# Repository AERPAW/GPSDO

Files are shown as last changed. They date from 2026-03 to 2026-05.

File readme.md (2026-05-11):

# AERPAW GPSDO

This repository contains the firmware, host utilities and design files for the AERPAW GPSDO.

The firmware is available in `firmware/` and the status utility in `gpsdo_status/`. See the readme in each for more information.

Install `gpsdo_cli` on Linux:

```sh
curl -fsSL https://raw.githubusercontent.com/AERPAW/GPSDO/main/gpsdo_cli/gpsdo_cli.py | sudo install -m 0755 /dev/stdin /usr/local/bin/gpsdo_cli
```

If `gpsdo_cli` cannot access `/dev/ttyACM*`, add your user to the serial device group and log out/in:

```sh
sudo usermod -aG dialout "$USER"
```

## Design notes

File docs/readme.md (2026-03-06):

# GPSDO Rev. 4.0 Documentation

## Overview

This document describes the 4th revision of the AERPAW GPSDO as well as the associated firmware and software. First, the hardware is described and all its function blocks are explained in detail. Then, the process of assembling and testing the GPSDO is explained. The firmware and host software, as well as the way to compile them is then finally explained.

TODO: Picture

## Hardware

This section describes the GPSDO hardware, a picture of which is shown below. A full schematic of the board can be found in the KiCad files.

TODO: Picture

- **10MHz Connector:** The 10MHz connector provides a 10MHz refernce signal for use by a USRP or other SDR.
- **1PPS Connector:** The 1-Pulse-Per-Second (1PPS) connector provides a pulse every second. This signal is 3.3V CMOS.
- **OCXO Data LED:** The OCXO Data LED blinks when data is exchanged between the OCXO module and host PC.
- **GNSS Data LED:** The GNSS Data LED blinks when data is exchanged between the GNSS module and host PC.
- **1PPS LED:** The 1PPS LED blinks once per second in phase with the 1PPS output.
- **OCXO Lock LED:** The OCXO Lock LED lights up when the OCXO has been able to lock onto the 1PPS signal from the GNSS module.
- **Power LED:** The power LED lights up any time the board receives power from either USB or the power connector.
- **USB Connector:** The USB connector allows a host computer to communicate with the on-board GNSS and OCXO modules.
- **Power Connector:** The power connector is used to provide 5 to 15V to the GPSDO.

### Theory of Operation

This section describes the inner workings of the GPSDO hardware, a block diagram of which is shown below. First, the power section and various safety features are described. Then, the GNSS and OCXO modules are described and the choice to use an external GNSS module is explained. Finally, the microcontroller section and its components is described.

TODO: Block diagram

#### Power Section

The power section takes 5 to 15V, either from the dedicated power connector or USB, filters it to attenuated noise from the incoming supply and regulates it down to 3.3V. The filter is implemented as simple common-mode choke. The power section also includes a series of protection features to ensure reliability and resiliance to mishandling. The incoming power is directed through a Schottky diode, a polyfuse and then is clamped by a 15V TVS diode. In the event that the board is powered in the wrong polarity, the board will simply not power on and no damage will be made. In the event that the 15V voltage limit is exceeded, the the TVS diode clamps it and the high resulting high current trips the polyfuse. Since polyfuses self reset when power is removed for a certain amount of time, no lasting damage is done. The schematic of the power section is as shown below.

TODO: Schematic.

#### GNSS Module

The GNSS module is an off-the-shelf SparkFun ZED-F9T breakout board. It's job is to receive GPS signals from the antenna connected to its input and generate a 1-Pulse-Per-Second (1PPS) signal that the OCXO module discussed further down can lock onto to generate a stable 10MHz. The module communicates with the microcontroller over a UART connection operating at 38400baud 8n1 (8bits, no parity, 1 stop bit).

#### OCXO Module

The OCXO module is actually originally an entire GPSDO in itself. Unfortunately, the GNSS portion of it was not satisfactory, so the external GNSS module is used to provide it with a 1PPS signal that it can lock onto. The module then generates a 10MHz signal from which it generates its own 1PPS signal. By comparing the phase of its 1PPS signal to the one from the GNSS module, it is able to steer the frequency of its oscillator slowly until the 1PPS signals are phase locked together. When this occurs, the Lock LED on the board lights up and the GPSDO is ready for operation. The OCXO module communicates with the microcontroller over a UART connections operating at 115200baud 8n1.

#### Microcontroller

The microcontroller is a Raspberry Pi RP2040. Its job is to relay the communication from the GNSS and OCXO modules to the host computer through a USB interface. It loads its firmware from the on-board flash memory and gets its clock from a separate 12MHz oscillator.

### Assembly

This section describes the process of assembling the GPSDO hardware from blank PCBs and components. This process can be summarized as follows: First, solder paste is applied to the PCB with the help of a stencil. Next, the intergrated circuits are placed, followed by small passives, then larger passives and finally the SMA connectors. The board can then be reflowed, after which the through-hole components can be soldered in manually. At this stage, the 3.3V voltage rail is checked and, if within the allowable range, the GNSS and OCXO modules are installed.

In general, it is recommended to have a computer on hand with the KiCad files open to be able to quickly find the location and orientation of all components. It is also helpful to figure out which traces carry which signals if debugging is necessary.

#### Solder Paste Application

The solder paste is applied using a solder paste stencil. This is simply a thin piece of stainless steel with precisely cut holes which are designed to let a specific quantity of solder paste in specific areas. To use the stencil, it is recommended to build a holding jig with other PCBs to hold the blank GPSDO PCB in place while the stencil is lowered onto it and solder paste is applied as shown in the picture below.

TODO: Picture

The paste can then be applied by first laying down a beed of solder paste onto one side of the stencil and dragging it across using a Squeegee as sown in the picture below.

TODO: Picture

The stencil can then be lifted revealing the paste applied to the pads on the PCB.

#### Placing the Integrated Circuits

Once the solder paste has been applied, the first components to be placed are the integrated circuits. This is done because they have a very small pin pitch and thus require a decent amount of precision to place. Having other components already on the board could make this more difficult. The board was designed such that all ICs are in the exact same orientation, with pin 1 oriented towards the top-left corner of the board, aka. the corner with the large power connector. The integrated circuits to place are as shown in the picture below.

TODO: Picture

#### Placing the Small Passives

After the integrated circuits are placed, all the 0805-sized passives can be placed. This includes all decoupling capacitors around the MCU, all resistors, a few small diodes and the polyfuse. The small passives are shown in the picture below.

TODO: Picture

#### Placing the Large Passives

The next components to be placed are the larger passives. This includes the inductors, the large TVS diode and the large decoupling capacitors for the switching voltage regulator. These large passives are as shown in the picture below.

TODO: Picture

#### Placing the SMA Connectors

Once all other SMD components have been places, the SMA connectors can be placed. To do this, simply slide the connectors over the edge of the PCB and make sure they are aligned properly with the pads as shown in the picture below.

TODO: Picture

#### Reflowing

With all SMD components now placed, the board can be reflowed. This involves heating up the board to melt the solder paste. To do this, places the PCBs in the reflow oven with dummy PCBs serving as spacers to make sure the PCBs do not touch the botton of the reflow oven as shown in the picture below. Then, close the oven tray and start the reflow process.

TODO: Picture

Once the oven indicates that the reflow process is over, open the tray and wait a few minutes for the board to cool down further.

#### Checking for Solder Bridges

Manual solder paste application and component placement is not perfect. After reflow soldering, it is likely that solder bridges will be left, most often on the pins of the integrated circuits. If any bridges are found, DO NOT proceed further until they are remedied as described below.

#### Soldering the Through-Hole Components

Now that all SMD components have been soldered using reflow soldering, the through-hole components can be soldered manually. The throughole components are as shown in the picture below.

TODO: Picture

> [!CAUTION]
> DO NOT install the GNSS and OCXO modules at this stage. The voltage regulator could be defective and cause a high voltage to appear on the 3.3V rail. This could easily destroy the expensive GNSS and OCXO modules.

#### Verifying the 3.3V Rail

With all components solder, the board can now be powered from the power connector. A multimeter is then used to measure the 3.3V rail at the point shown in the picture below. The measured voltage must be in the range of 3.2 to 3.4V for the board to be considered working at this stage.

TODO: Picture

#### Ultrasonic Cleaning

Once the power section has been confirmed to be working, the board can be cleaned using the ultrasonic cleaner to remove all flux residue.

#### Installing the GNSS and OCXO modules

The last step in the assembly process is simply installing the GNSS and OCXO modules. While the GNSS module is straight foward to install, caution must be used when installing the OCXO module due to its thin pins that easily bend and break.

### Bring-Up

With the GPSDO fully assembled, power is applied through the power connector and the USB port is connected to a computer. The GPSDO should appear as a USB flash drive.

#### Flashing the firmware

To flash the firmware, simply drag and drop the .UF2 firmware file to the virtual USB flash drive. The board should then reboot, after which you should see two virtual serial ports.

#### Configuring the OCXO Module

Out of the box, the OCXO modules are not configured to lock from an external 1PPS. To configure this, open the serial port corresponding to the OCXO module in a virtual terminal and run the following commands:

```
SYNC?
SYNC:SOUR:MODE EXT
SYNC?
```

This configuration is stored in non-volatile memory on the module and thus only has to be done once. After this, the OCXO module should now attempt to lock onto the 1PPS signal from the GNSS module.

#### Troubleshooting

TODO

### Testing

TODO

## Firmware

This section describes the firmware of the GPSDO, that is the code that runs on the embedded microcontroller.

### Theory of Operation

### Compilation

## Software

### Theory of Operation

### Compilation

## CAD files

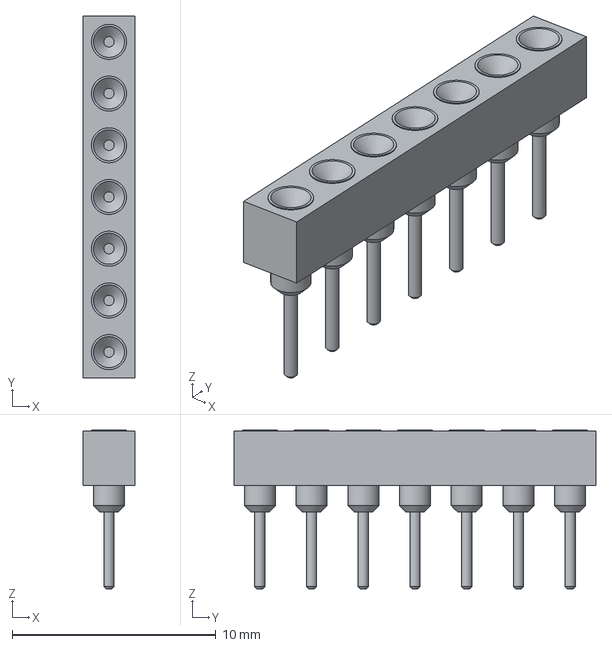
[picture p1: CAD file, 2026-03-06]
pcb/3d/sip7.step
2.54 x 17.8 x 7.79 mm

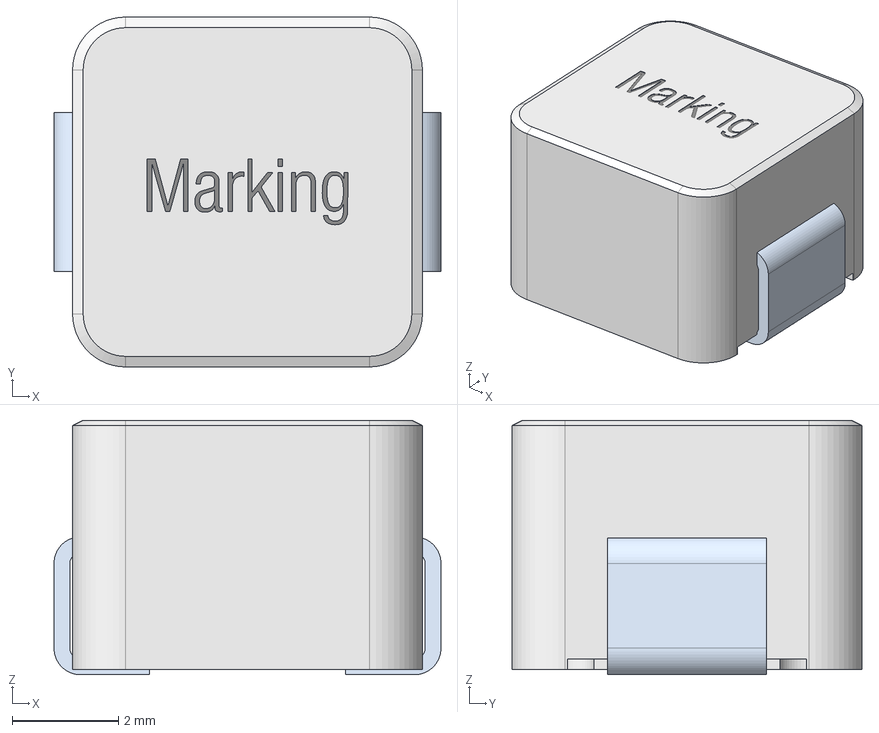
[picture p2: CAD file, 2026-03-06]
pcb/3d/WE-LHMI_7050LHMI (rev1).stp
7.30 x 6.60 x 4.80 mm

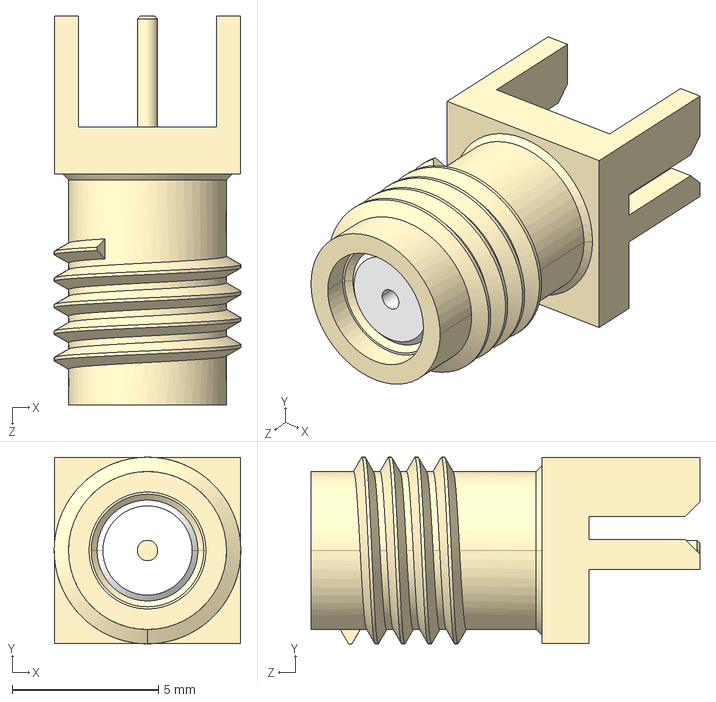
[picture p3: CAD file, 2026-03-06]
pcb/3d/EMPCB.SMAFSTJ.B.HT.STEP
6.38 x 6.38 x 13.3 mm

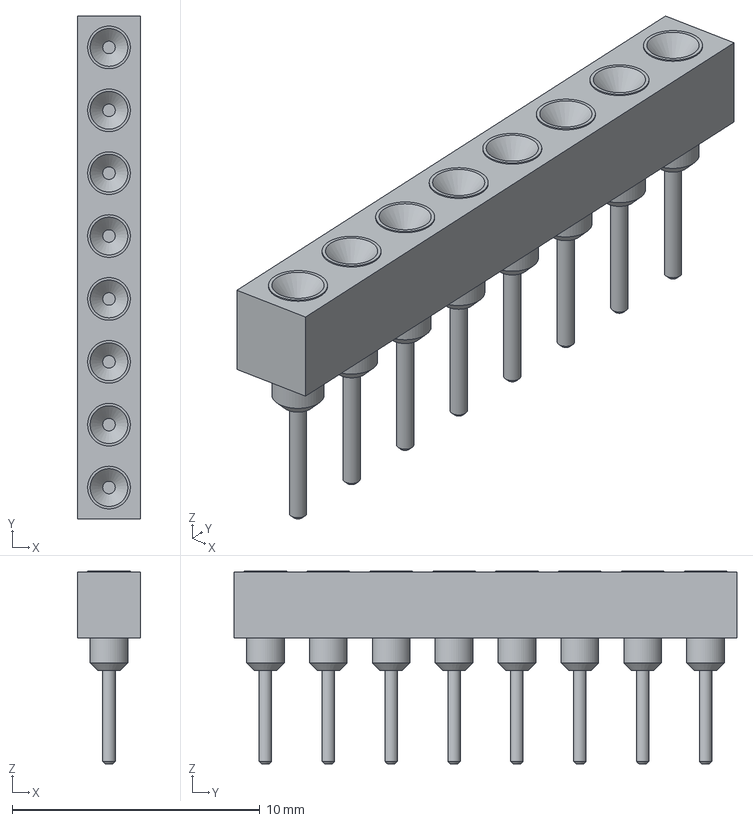
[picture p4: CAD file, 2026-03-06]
pcb/3d/sip8.step
2.54 x 20.3 x 7.79 mm

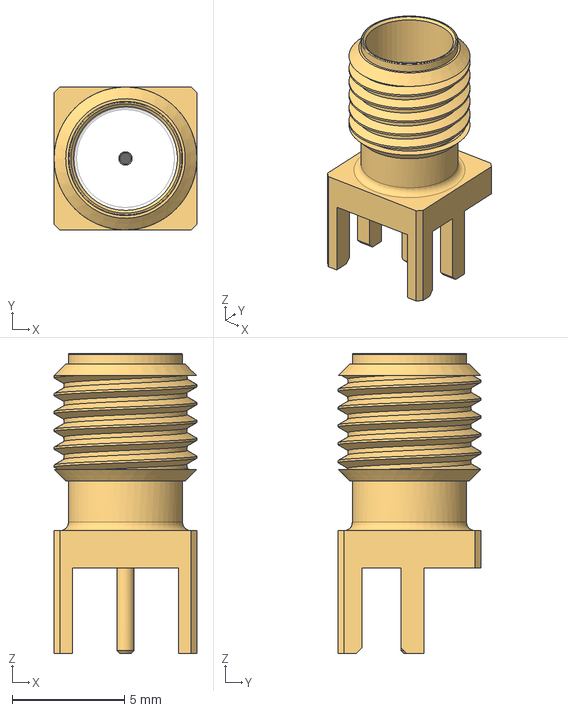
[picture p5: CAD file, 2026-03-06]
pcb/3d/BU-1420711821.stp
6.35 x 6.35 x 13.3 mm

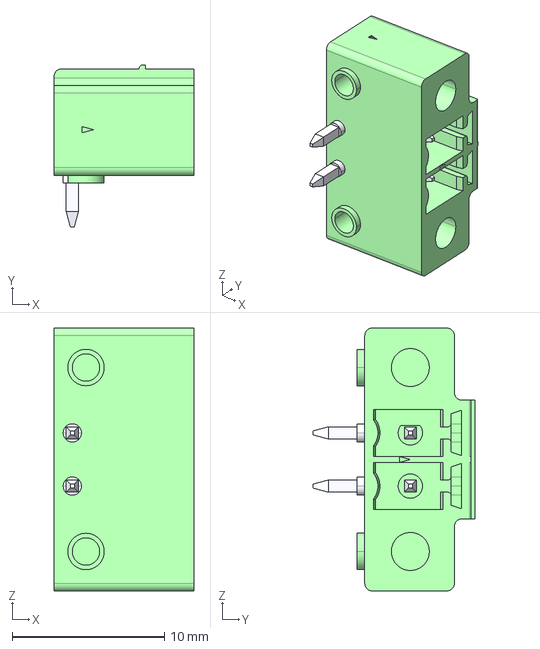
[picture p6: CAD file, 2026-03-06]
pcb/3d/1843790.stp
9.20 x 10.7 x 17.3 mm

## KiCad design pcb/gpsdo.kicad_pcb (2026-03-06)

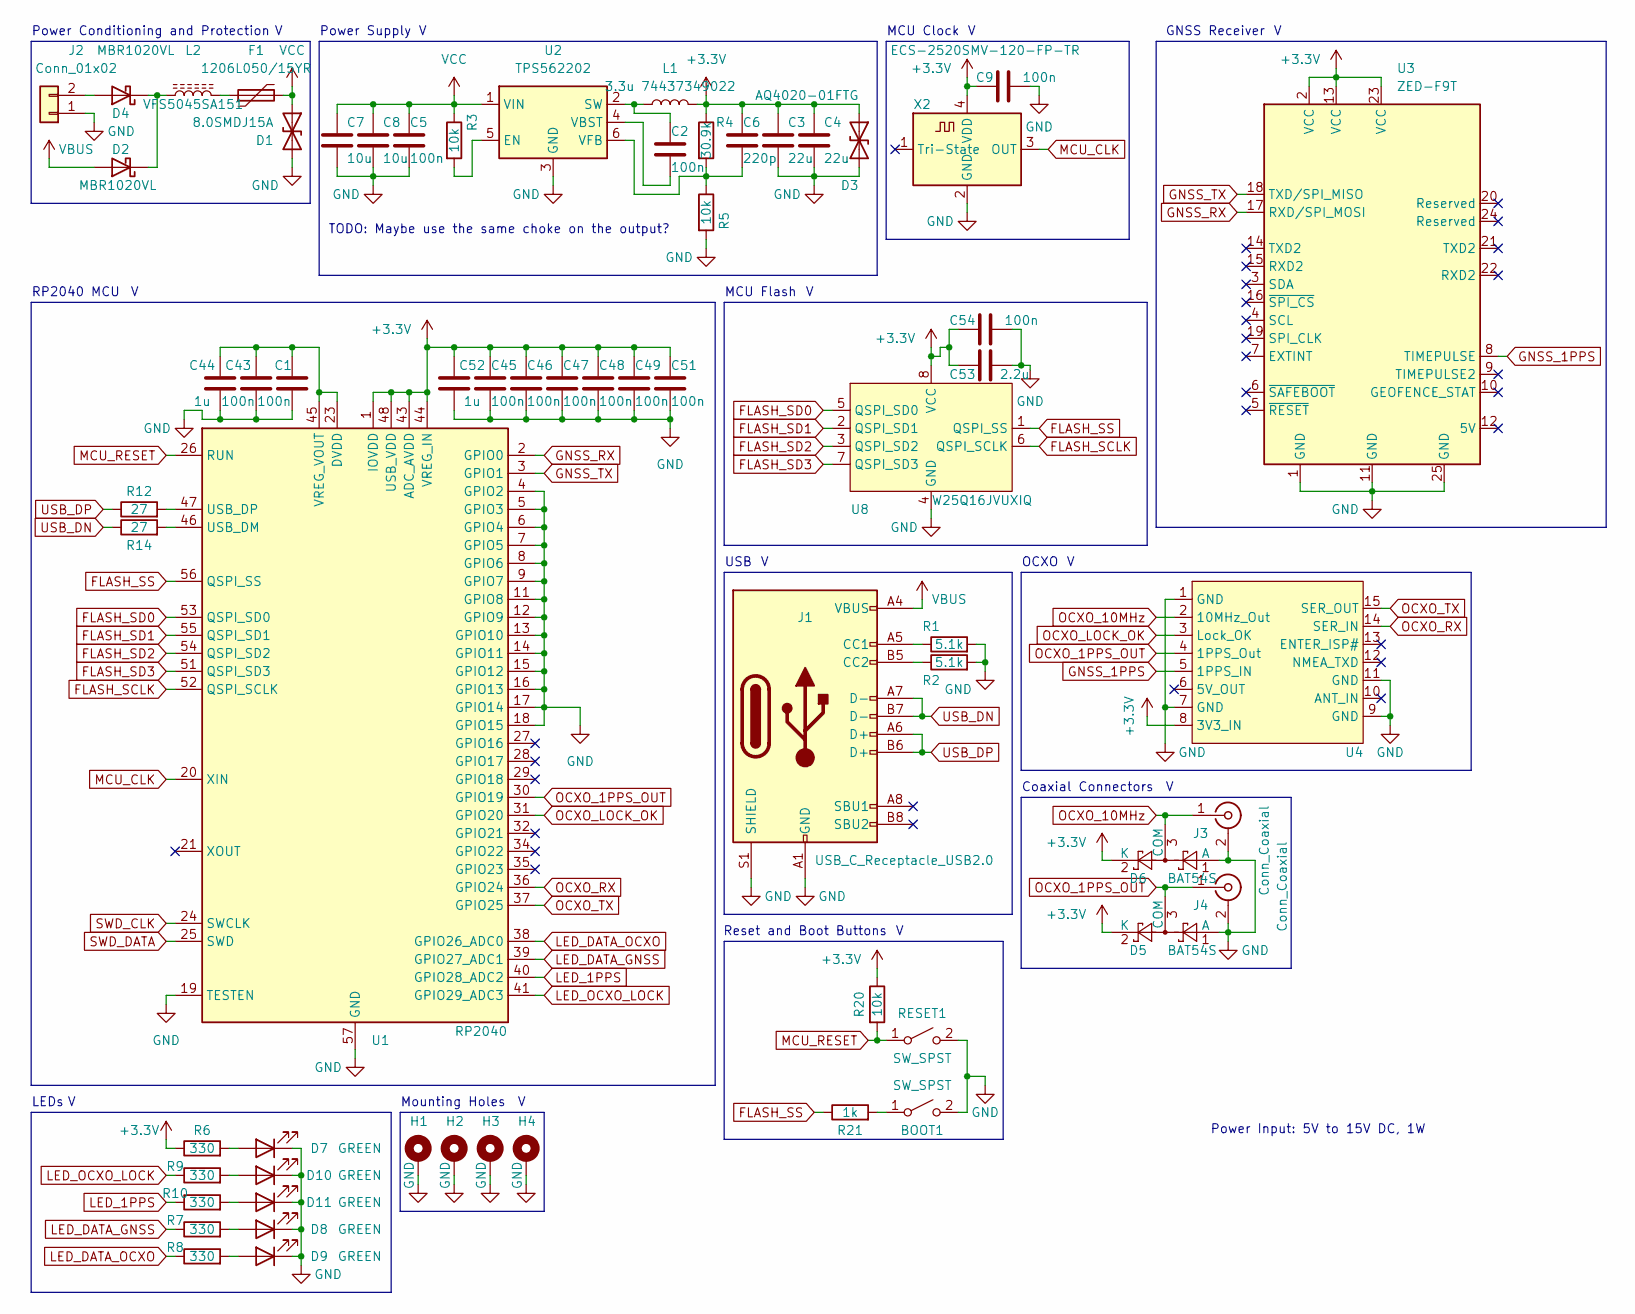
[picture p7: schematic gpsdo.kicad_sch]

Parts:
BOOT1: SW_SPST; SW_SPST_B3U-1000P-B
C1, C2, C5, C9, C43, C45, C46, C47, C48, C49, C51, C54: 100n; C_0805_2012Metric_Pad1.18x1.45mm_HandSolder
C3, C4: 22u; C_1210_3225Metric_Pad1.33x2.70mm_HandSolder
C6: 220p; C_0805_2012Metric_Pad1.18x1.45mm_HandSolder
C7, C8: 10u; C_0805_2012Metric_Pad1.18x1.45mm_HandSolder
C44, C52: 1u; C_0805_2012Metric_Pad1.18x1.45mm_HandSolder
C53: 2.2u; C_0805_2012Metric_Pad1.18x1.45mm_HandSolder
D1: 8.0SMDJ15A; D_SMC_Handsoldering
D2, D4: MBR1020VL; D_SOD-123F
D3: AQ4020-01FTG; D_SOD-323_HandSoldering
D5, D6: BAT54S; SOT-23
D7, D8, D9, D10, D11: GREEN; LED_0805_2012Metric_Pad1.15x1.40mm_HandSolder
F1: 1206L050/15YR; Fuse_1206_3216Metric_Pad1.42x1.75mm_HandSolder
H1, H2, H3, H4: MountingHole_Pad; MountingHole_3.2mm_M3_DIN965_Pad
J1: USB_C_Receptacle_USB2.0; USB_C_Receptacle_GCT_USB4105-xx-A_16P_TopMnt_Horizontal
J2: Conn_01x02; CONN_1843790
J3, J4: Conn_Coaxial; TAOGLAS_EMPCB.SMAFSTJ.B.HT
L1: 3.3u 74437349022; 74437349022
L2: VFS5045SA151; L_APV_ANR5045
R1, R2: 5.1k; R_0805_2012Metric_Pad1.20x1.40mm_HandSolder
R3, R5, R20: 10k; R_0805_2012Metric_Pad1.20x1.40mm_HandSolder
R4: 30.9k; R_0805_2012Metric_Pad1.20x1.40mm_HandSolder
R6, R7, R8, R9, R10: 330; R_0805_2012Metric_Pad1.20x1.40mm_HandSolder
R12, R14: 27; R_0805_2012Metric_Pad1.20x1.40mm_HandSolder
R21: 1k; R_0805_2012Metric_Pad1.20x1.40mm_HandSolder
RESET1: SW_SPST; SW_SPST_B3U-1000P-B
U1: RP2040; QFN-56-1EP_7x7mm_P0.4mm_EP3.2x3.2mm
U2: TPS562202; SOT-563
U3: ZED-F9T; MODULE_GPS-15136
U4: 15 Pin GPSDO
U8: W25Q16JVUXIQ; SON50P300X200X60-9N
X2: ECS-2520SMV-120-FP-TR; Oscillator_SMD_ECS_2520MV-xxx-xx-4Pin_2.5x2.0mm

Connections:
+3.3V: C3.1, C4.1, C6.1, C9.1, C45.1, C46.1, C47.1, C48.1, C49.1, C51.1, C52.2, C53.1, C54.1, D3.1 (A1), D5.2 (K), D6.2 (K), L1.2, R4.1, R6.1, R20.1, U1.1 (IOVDD), U1.10 (IOVDD), U1.22 (IOVDD), U1.33 (IOVDD), U1.42 (IOVDD), U1.43 (ADC_AVDD), U1.44 (VREG_IN), U1.48 (USB_VDD), U1.49 (IOVDD), U3.2 (VCC), U3.13 (VCC), U3.23 (VCC), U4.8 (3V3_IN), U8.8 (VCC), X2.4 (VDD)
FLASH_SCLK: U1.52 (QSPI_SCLK), U8.6 (QSPI_SCLK)
FLASH_SD0: U1.53 (QSPI_SD0), U8.5 (QSPI_SD0)
FLASH_SD1: U1.55 (QSPI_SD1), U8.2 (QSPI_SD1)
FLASH_SD2: U1.54 (QSPI_SD2), U8.3 (QSPI_SD2)
FLASH_SD3: U1.51 (QSPI_SD3), U8.7 (QSPI_SD3)
FLASH_SS: R21.1, U1.56 (QSPI_SS), U8.1 (QSPI_SS)
GND: BOOT1.2 (B), C1.1, C3.2, C4.2, C5.2, C7.2, C8.2, C9.2, C43.1, C44.1, C45.2, C46.2, C47.2, C48.2, C49.2, C51.2, C52.1, C53.2, C54.2, D1.2 (A2), D3.2 (A2), D5.1 (A), D6.1 (A), D7.1 (K), D8.1 (K), D9.1 (K), D10.1 (K), D11.1 (K), H1.1, H2.1, H3.1, H4.1, J1.A1 (GND), J1.A12 (GND), J1.B1 (GND), J1.B12 (GND), J1.S1 (SHIELD), J2.1, J3.2 (Ext), J4.2 (Ext), R1.2, R2.2, R5.2, RESET1.2 (B), U1.4 (GPIO2), U1.5 (GPIO3), U1.6 (GPIO4), U1.7 (GPIO5), U1.8 (GPIO6), U1.9 (GPIO7), U1.11 (GPIO8), U1.12 (GPIO9), U1.13 (GPIO10), U1.14 (GPIO11), U1.15 (GPIO12), U1.16 (GPIO13), U1.17 (GPIO14), U1.18 (GPIO15), U1.19 (TESTEN), U1.57 (GND), U2.3 (GND), U3.1 (GND), U3.11 (GND), U3.25 (GND), U4.1 (GND), U4.7 (GND), U4.9 (GND), U4.11 (GND), U8.4 (GND), X2.2 (GND)
GNSS_1PPS: U3.8 (TIMEPULSE), U4.5 (1PPS_IN)
GNSS_RX: U1.2 (GPIO0), U3.17 (RXD/SPI_MOSI)
GNSS_TX: U1.3 (GPIO1), U3.18 (TXD/SPI_MISO)
LED_1PPS: R10.1, U1.40 (GPIO28_ADC2)
LED_DATA_GNSS: R7.1, U1.39 (GPIO27_ADC1)
LED_DATA_OCXO: R8.1, U1.38 (GPIO26_ADC0)
LED_OCXO_LOCK: R9.1, U1.41 (GPIO29_ADC3)
MCU_CLK: U1.20 (XIN), X2.3 (OUT)
MCU_RESET: R20.2, RESET1.1 (A), U1.26 (RUN)
unnamed: BOOT1.1 (A), R21.2
unnamed: D2.1 (K), D4.1 (K), L2.1
unnamed: D4.2 (A), J2.2
unnamed: D7.2 (A), R6.2
unnamed: D8.2 (A), R7.2
unnamed: D9.2 (A), R8.2
unnamed: D10.2 (A), R9.2
unnamed: D11.2 (A), R10.2
unnamed: F1.1, L2.2
unnamed: J1.A5 (CC1), R1.1
unnamed: J1.B5 (CC2), R2.1
unnamed: R14.2, U1.46 (USB_DM)
unnamed: R12.2, U1.47 (USB_DP)
unnamed: C1.2, C43.2, C44.2, U1.23 (DVDD), U1.45 (VREG_VOUT), U1.50 (DVDD)
unnamed: R3.2, U2.5 (EN)
unnamed: C2.1, L1.1, U2.2 (SW)
unnamed: C2.2, U2.4 (VBST)
unnamed: C6.2, R4.2, R5.1, U2.6 (VFB)
OCXO_1PPS_OUT: D5.3 (COM), J4.1 (In), U1.30 (GPIO19), U4.4 (1PPS_Out)
OCXO_10MHz: D6.3 (COM), J3.1 (In), U4.2 (10MHz_Out)
OCXO_LOCK_OK: U1.31 (GPIO20), U4.3 (Lock_OK)
OCXO_RX: U1.36 (GPIO24), U4.14 (SER_IN)
OCXO_TX: U1.37 (GPIO25), U4.15 (SER_OUT)
SWD_CLK: U1.24 (SWCLK)
SWD_DATA: U1.25 (SWD)
USB_DN: J1.A7 (D-), J1.B7 (D-), R14.1
USB_DP: J1.A6 (D+), J1.B6 (D+), R12.1
VBUS: D2.2 (A), J1.A4 (VBUS), J1.A9 (VBUS), J1.B4 (VBUS), J1.B9 (VBUS)
VCC: C5.1, C7.1, C8.1, D1.1 (A1), F1.2, R3.1, U2.1 (VIN)

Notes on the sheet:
Reset and Boot Buttons
Power Conditioning and Protection
Power Supply
LEDs
Mounting Holes
Coaxial Connectors
RP2040 MCU
MCU Flash
Power Input: 5V to 15V DC, 1W
TODO: Maybe use the same choke on the output?
OCXO
USB
MCU Clock
GNSS Receiver

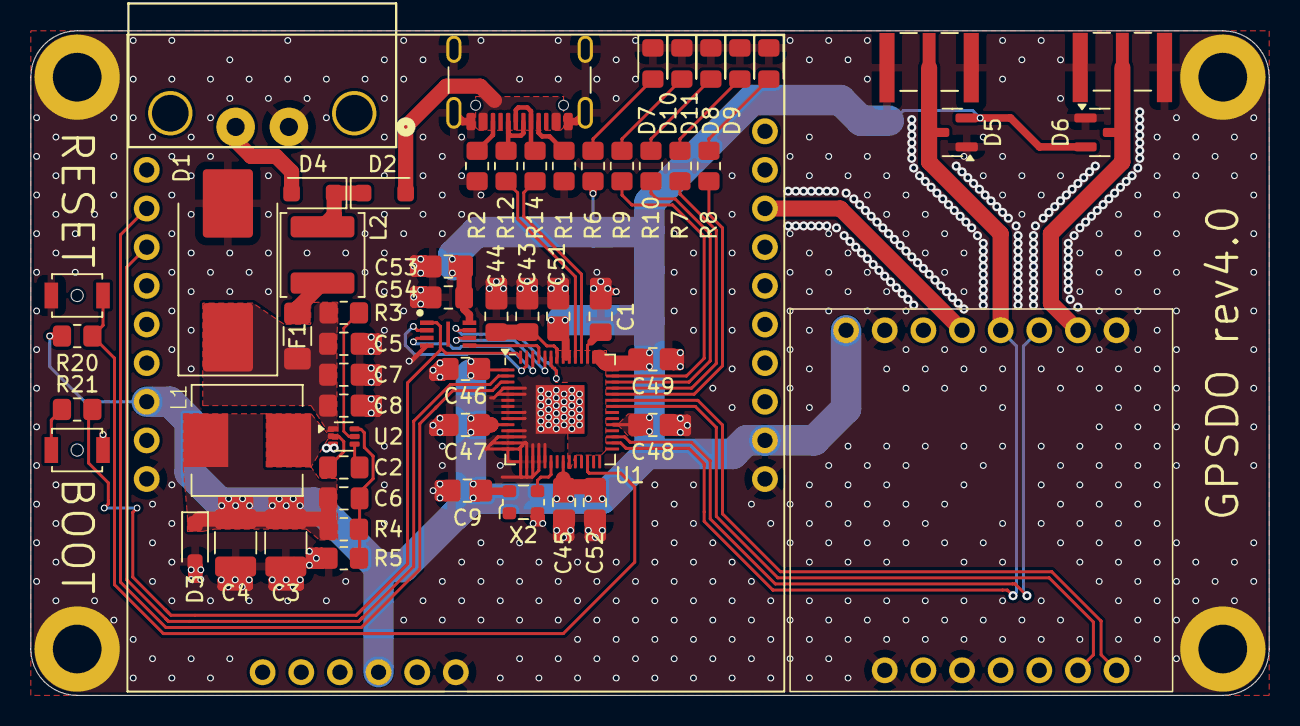
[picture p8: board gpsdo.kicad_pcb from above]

Board: 2 copper layers, 81.4 x 43.7 mm, 64 parts (0 on the bottom side), 44 nets.

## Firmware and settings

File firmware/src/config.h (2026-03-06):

#pragma once
#include <hardware/uart.h>

#define GNSS_CDC_IFACE      0
#define GNSS_UART           uart0
#define GNSS_TX_PIN         0
#define GNSS_RX_PIN         1
#define GNSS_DATA_LED_PIN   27

#define OCXO_CDC_IFACE      1
#define OCXO_UART           uart1
#define OCXO_TX_PIN         24
#define OCXO_RX_PIN         25
#define OCXO_1PPS_PIN       19
#define OCXO_LOCK_PIN       20
#define OCXO_DATA_LED_PIN   26
#define OCXO_1PPS_LED_PIN   28
#define OCXO_LOCK_LED_PIN   29


// Note: this is set to avoid uart writes taking too long
#define DEFAULT_GNSS_BAUDRATE   38400
#define DEFAULT_OCXO_BAUDRATE   115200
#define BUFFER_SIZE             64

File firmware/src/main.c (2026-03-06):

#include <tusb.h>
#include <stdio.h>
#include <pico/stdlib.h>
#include <pico/multicore.h>
#include <hardware/gpio.h>
#include <hardware/uart.h>
#include <hardware/irq.h>
#include "tusb_config.h"
#include "class/cdc/cdc_device.h"
#include "class/cdc/cdc.h"
#include "config.h"
#include "tasks/serial_relay_task.h"
#include "tasks/blinking_led_task.h"

blinking_led_task_t gnss_data_led_task;
blinking_led_task_t ocxo_data_led_task;
blinking_led_task_t ocxo_1pps_led_task;

volatile bool irq_fired = false;
void pps_irq() {
    // Set the IRQ fired flag
    irq_fired = true;
}

void core1() {
    // Register the PPS interrupt handler
    gpio_set_irq_enabled_with_callback(OCXO_1PPS_PIN, GPIO_IRQ_EDGE_RISE, true, pps_irq);

    // Run the other tasks
    while (true) {
        // Check if the IRQ has fired
        if (irq_fired) {
            blinking_led_task_trigger(&ocxo_1pps_led_task);
            irq_fired = false;
        }

        // Run the LED blinking tasks
        blinking_led_task_run(&gnss_data_led_task);
        blinking_led_task_run(&ocxo_data_led_task);
        blinking_led_task_run(&ocxo_1pps_led_task);
        
        // Update the lock LED
        gpio_put(OCXO_LOCK_LED_PIN, gpio_get(OCXO_LOCK_PIN));
    }
}

int main() {
    // Initialize the two UARTs
    uart_init(GNSS_UART, DEFAULT_GNSS_BAUDRATE);
    uart_init(OCXO_UART, DEFAULT_OCXO_BAUDRATE);
    
    // Configure the uart pins
    gpio_set_function(GNSS_TX_PIN, UART_FUNCSEL_NUM(GNSS_UART, GNSS_TX_PIN));
    gpio_set_function(GNSS_RX_PIN, UART_FUNCSEL_NUM(GNSS_UART, GNSS_RX_PIN));
    gpio_set_function(OCXO_TX_PIN, UART_FUNCSEL_NUM(OCXO_UART, OCXO_TX_PIN));
    gpio_set_function(OCXO_RX_PIN, UART_FUNCSEL_NUM(OCXO_UART, OCXO_RX_PIN));

    // Initialize the 1PPS and lock inputs
    gpio_init(OCXO_1PPS_PIN);
    gpio_set_dir(OCXO_1PPS_PIN, false);
    gpio_set_dir(OCXO_LOCK_PIN, false);

    // Initialize the status LEDs
    gpio_init(GNSS_DATA_LED_PIN);
    gpio_init(OCXO_DATA_LED_PIN);
    gpio_init(OCXO_1PPS_LED_PIN);
    gpio_init(OCXO_LOCK_LED_PIN);
    gpio_set_dir(GNSS_DATA_LED_PIN, true);
    gpio_set_dir(OCXO_DATA_LED_PIN, true);
    gpio_set_dir(OCXO_1PPS_LED_PIN, true);
    gpio_set_dir(OCXO_LOCK_LED_PIN, true);
    gpio_put(GNSS_DATA_LED_PIN, 0);
    gpio_put(OCXO_DATA_LED_PIN, 0);
    gpio_put(OCXO_1PPS_LED_PIN, 0);
    gpio_put(OCXO_LOCK_LED_PIN, 0);

    // Initialize the LED blinking tasks
    blinking_led_task_init(&gnss_data_led_task, GNSS_DATA_LED_PIN, 100);
    blinking_led_task_init(&ocxo_data_led_task, OCXO_DATA_LED_PIN, 100);
    blinking_led_task_init(&ocxo_1pps_led_task, OCXO_1PPS_LED_PIN, 100);

    // Initialize TinyUSB
    tusb_init();

    // Start the second core
    multicore_launch_core1(core1);

    // Run USB task
    while (true) {
        // TinyUSB task
        tud_task();

        // Relay the serial ports
        serial_relay_task(GNSS_UART, GNSS_CDC_IFACE, &gnss_data_led_task);
        serial_relay_task(OCXO_UART, OCXO_CDC_IFACE, &ocxo_data_led_task);
    }

    return 0;
}

// uart_parity_t PARITY_MAP[] = {
//     UART_PARITY_NONE,
//     UART_PARITY_ODD,
//     UART_PARITY_EVEN,
//     UART_PARITY_NONE, // NOTE: These will not work
//     UART_PARITY_NONE  // NOTE: These will not work
// };

// // Handler called by TinyUSB when the interface
// void tud_cdc_line_coding_cb(uint8_t itf, cdc_line_coding_t const* line_coding) {
//     // Handle depending on the interface
//     switch (itf) {
//     case GNSS_CDC_IFACE:
//         uart_set_baudrate(GNSS_UART, line_coding->bit_rate);
//         uart_set_format(GNSS_UART, line_coding->data_bits, line_coding->stop_bits, PARITY_MAP[line_coding->parity]);
//         break;
//     case OCXO_CDC_IFACE:
//         uart_set_baudrate(OCXO_UART, line_coding->bit_rate);
//         uart_set_format(OCXO_UART, line_coding->data_bits, line_coding->stop_bits, PARITY_MAP[line_coding->parity]);
//         break;
//     }
// }

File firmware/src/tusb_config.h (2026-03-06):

/*
 * The MIT License (MIT)
 *
 * Copyright (c) 2019 Ha Thach (tinyusb.org)
 *
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
 */

#ifndef _TUSB_CONFIG_H_
#define _TUSB_CONFIG_H_

#ifdef __cplusplus
 extern "C" {
#endif

//--------------------------------------------------------------------
// CDC CONFIGURATION
//--------------------------------------------------------------------
#define CFG_TUD_CDC_RX_BUFSIZE 8192
#define CFG_TUD_CDC_TX_BUFSIZE 8192

//--------------------------------------------------------------------
// COMMON CONFIGURATION
//--------------------------------------------------------------------

// defined by board.mk
#ifndef CFG_TUSB_MCU
  #error CFG_TUSB_MCU must be defined
#endif

// RHPort number used for device can be defined by board.mk, default to port 0
#ifndef BOARD_DEVICE_RHPORT_NUM
  #define BOARD_DEVICE_RHPORT_NUM     0
#endif

// RHPort max operational speed can defined by board.mk
// Default to Highspeed for MCU with internal HighSpeed PHY (can be port specific), otherwise FullSpeed
#ifndef BOARD_DEVICE_RHPORT_SPEED
  #if (CFG_TUSB_MCU == OPT_MCU_LPC18XX || CFG_TUSB_MCU == OPT_MCU_LPC43XX || CFG_TUSB_MCU == OPT_MCU_MIMXRT10XX || \
       CFG_TUSB_MCU == OPT_MCU_NUC505  || CFG_TUSB_MCU == OPT_MCU_CXD56 || CFG_TUSB_MCU == OPT_MCU_SAMX7X)
    #define BOARD_DEVICE_RHPORT_SPEED   OPT_MODE_HIGH_SPEED
  #else
    #define BOARD_DEVICE_RHPORT_SPEED   OPT_MODE_FULL_SPEED
  #endif
#endif

// Device mode with rhport and speed defined by board.mk
#if   BOARD_DEVICE_RHPORT_NUM == 0
  #define CFG_TUSB_RHPORT0_MODE     (OPT_MODE_DEVICE | BOARD_DEVICE_RHPORT_SPEED)
#elif BOARD_DEVICE_RHPORT_NUM == 1
  #define CFG_TUSB_RHPORT1_MODE     (OPT_MODE_DEVICE | BOARD_DEVICE_RHPORT_SPEED)
#else
  #error "Incorrect RHPort configuration"
#endif

#ifndef CFG_TUSB_OS
#define CFG_TUSB_OS               OPT_OS_NONE
#endif

// CFG_TUSB_DEBUG is defined by compiler in DEBUG build
// #define CFG_TUSB_DEBUG           0

/* USB DMA on some MCUs can only access a specific SRAM region with restriction on alignment.
 * Tinyusb use follows macros to declare transferring memory so that they can be put
 * into those specific section.
 * e.g
 * - CFG_TUSB_MEM SECTION : __attribute__ (( section(".usb_ram") ))
 * - CFG_TUSB_MEM_ALIGN   : __attribute__ ((aligned(4)))
 */
#ifndef CFG_TUSB_MEM_SECTION
#define CFG_TUSB_MEM_SECTION
#endif

#ifndef CFG_TUSB_MEM_ALIGN
#define CFG_TUSB_MEM_ALIGN          __attribute__ ((aligned(4)))
#endif

//--------------------------------------------------------------------
// DEVICE CONFIGURATION
//--------------------------------------------------------------------

#ifndef CFG_TUD_ENDPOINT0_SIZE
#define CFG_TUD_ENDPOINT0_SIZE    64
#endif

//------------- CLASS -------------//
#define CFG_TUD_HID               0
#define CFG_TUD_CDC               2
#define CFG_TUD_MSC               0
#define CFG_TUD_MIDI              0
#define CFG_TUD_VENDOR            0

#ifdef __cplusplus
 }
#endif

#endif /* _TUSB_CONFIG_H_ */

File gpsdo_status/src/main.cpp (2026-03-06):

#include <stdio.h>
#include <stdexcept>
#include "cli/cli.h"
#include "ansi/ansi.h"
#include "gpsdo.h"
#include "version.h"

// ANSI escape code macros for human-readable output
#define ANSI_RED    ANSI_CSI ANSI_SGR_FG_BRIGHT_RED
#define ANSI_GREEN  ANSI_CSI ANSI_SGR_FG_BRIGHT_GREEN
#define ANSI_RESET  ANSI_CSI ANSI_SGR_RESET

/**
 * Show the help dialog for the software given its command line interface.
 * @param iface Command line interface for the software.
*/
void showHelp(const cli::Interface& iface) {
    // Show the software version
    printf("gpsdo_status v" GPSDO_STATUS_VERSION "\n\n");

    // Show all valid command line arguments
    for (auto& [ name, arg ] : iface.arguments) {
        // Find the alias corresponding to the argument
        auto it = std::find_if(iface.aliases.begin(), iface.aliases.end(), [&name](std::pair<char, std::string> pair){ return pair.second == name; });
        
        // If found, save it, otherwise set it to null
        char alias = 0;
        if (it != iface.aliases.end()) { alias = it->first; }
        
        

    }
}

int main(int argc, char** argv) {
    try {
        // Define the command-line interface
        cli::Interface iface;
        iface.arg("gnss-port", 'g', "",    "Serial port used for the GNSS module");
        iface.arg("tcxo-port", 't', "",    "Serial port used for the TCXO module");
        iface.arg("json",      'j', false, "Show the status in software-readbale JSON format");
        iface.arg("help",      'h', false, "Show the help screen");

        // Parse the command line arguments
        auto cmd = cli::parse(iface, argc, argv);

        // If the help screen was requested, show it and exit
        if (cmd["help"] || argc == 1) {
            // Show the help screen
            showHelp(iface);

            // Exit successfully
            return 0;
        }

        // Make sure two ports were given
        std::string gnssPort = cmd["gnss-port"];
        std::string tcxoPort = cmd["tcxo-port"];
        if (gnssPort.empty() || tcxoPort.empty()) { throw std::runtime_error("Both a GNSS and TCXO port must be provided"); }

        // Open the device
        auto dev = gpsdo::open(gnssPort, tcxoPort);

        // Query the status
        bool gnssLocked = dev.gnssLocked();
        bool tcxoLocked = dev.tcxoLocked();

        // Display the status in the requested format
        if (cmd["json"]) {
            // Encode the status in JSON
            printf("{ \"gnssLocked\": %s, \"tcxoLocked\": %s }\n", gnssLocked ? "true":"false", tcxoLocked ? "true":"false");
        }
        else {
            // Show the status in a human-readable format
            printf("GNSS: %s\n" ANSI_RESET, gnssLocked ? ANSI_GREEN "Locked" : ANSI_RED "UNLOCKED");
            printf("TCXO: %s\n" ANSI_RESET, tcxoLocked ? ANSI_GREEN "Locked" : ANSI_RED "UNLOCKED");
        }

        // Exit succesfully
        return 0;
    }
    catch (const std::exception& e) {
        // Display the error
        fprintf(stderr, "ERROR: %s\n", e.what());
        
        // Exit unsuccessfully
        return -1;
    }
}
